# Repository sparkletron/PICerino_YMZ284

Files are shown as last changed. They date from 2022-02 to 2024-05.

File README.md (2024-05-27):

# PICerino YMZ284

Test Board and Software Library for Yamaha YMZ284 sound chips.

author: Jay Convertino  

date: 2024.04.21

license: MIT (software/Hardware)

## Release Versions
### Current
  - release_v1

### Past
  - none
  
## Requirements
### Hardware
  - KiCad
  
### Software
  - xc8 compiler
  
### General Information

Directory Listing:  

  - docs - Data documents for various ICs.
  - schematic - KiCad schematic of YMZ284 test board. See readme.md in dir for details.
  - src - Any source code for the project.
    - lib_picYMZ284 - library with test program for picerino. See readme.md in dir for details.

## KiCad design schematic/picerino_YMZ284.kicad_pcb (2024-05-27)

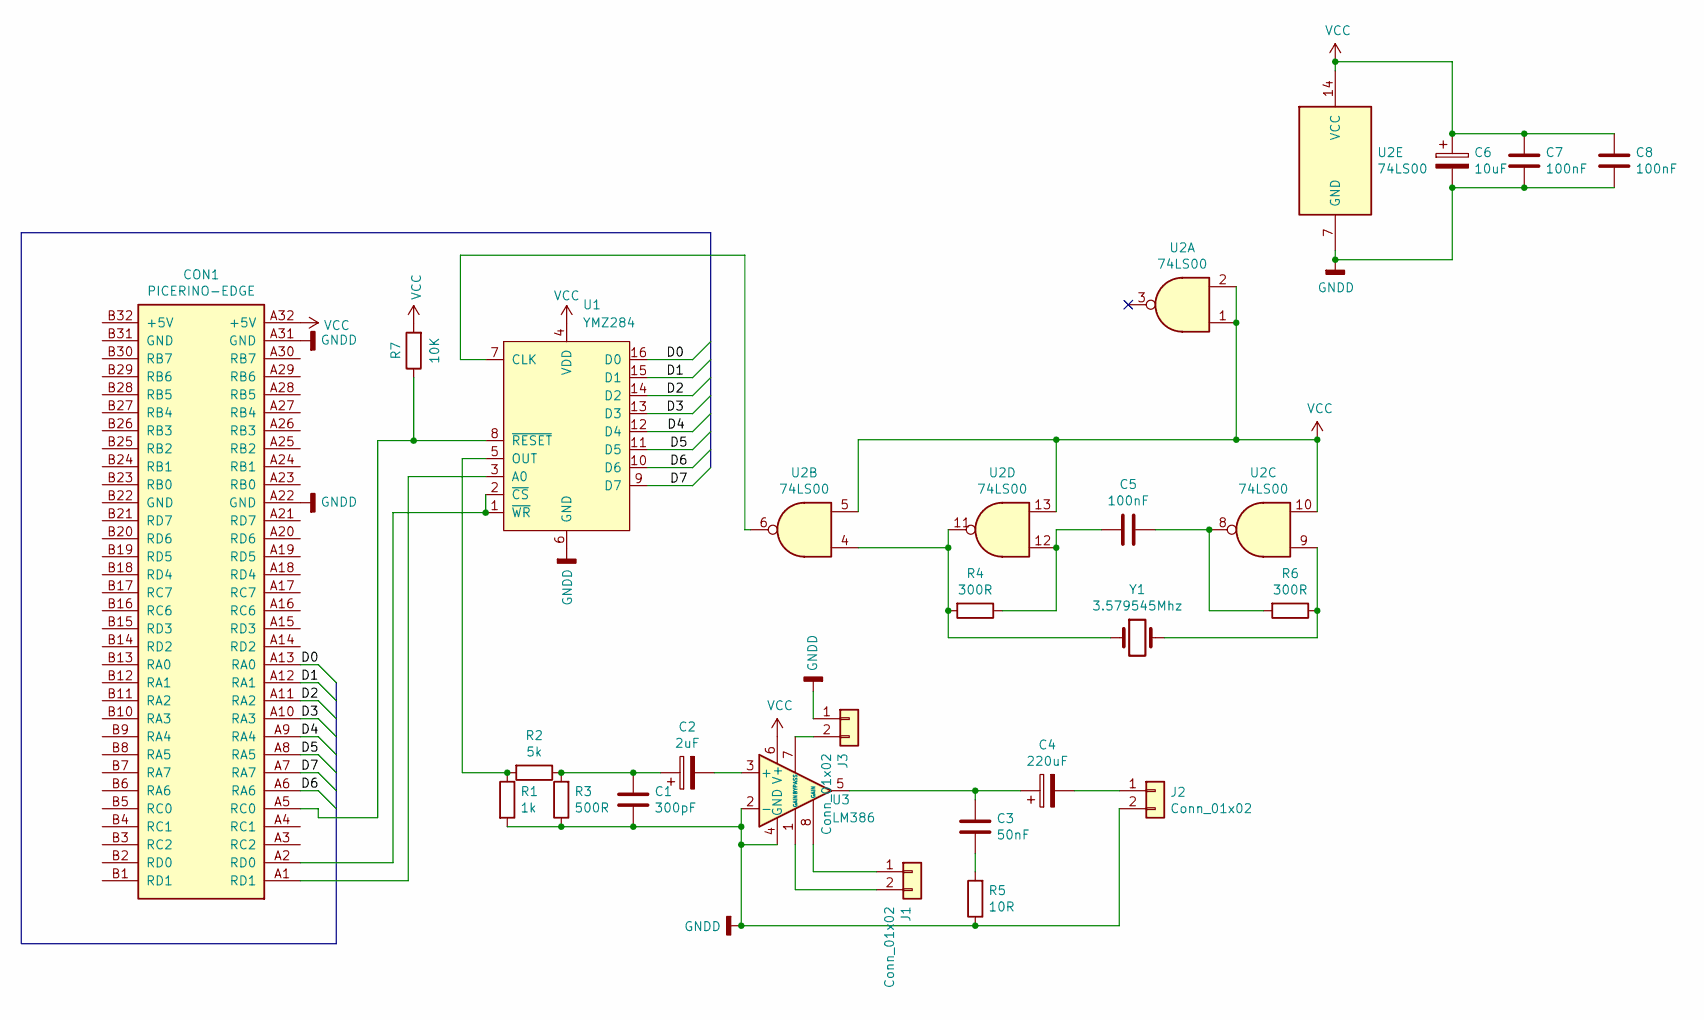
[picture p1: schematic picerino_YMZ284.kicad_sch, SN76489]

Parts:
C1: 300pF; C_Disc_D4.7mm_W2.5mm_P5.00mm
C2: 2uF; CP_Radial_D5.0mm_P2.50mm
C3: 50nF; C_Disc_D4.7mm_W2.5mm_P5.00mm
C4: 220uF; CP_Radial_D10.0mm_P5.00mm
C5, C7, C8: 100nF; C_Disc_D4.7mm_W2.5mm_P5.00mm
C6: 10uF; CP_Radial_D5.0mm_P2.50mm
CON1: PICERINO-EDGE; GENESIS-EDGE
J1, J3: Conn_01x02; PinHeader_1x02_P2.54mm_Vertical
J2: Conn_01x02; PhoenixContact_MSTBVA_2,5_2-G_1x02_P5.00mm_Vertical
R1: 1k; R_Axial_DIN0207_L6.3mm_D2.5mm_P7.62mm_Horizontal
R2: 5k; R_Axial_DIN0207_L6.3mm_D2.5mm_P7.62mm_Horizontal
R3: 500R; R_Axial_DIN0207_L6.3mm_D2.5mm_P7.62mm_Horizontal
R4, R6: 300R; R_Axial_DIN0207_L6.3mm_D2.5mm_P7.62mm_Horizontal
R5: 10R; R_Axial_DIN0207_L6.3mm_D2.5mm_P7.62mm_Horizontal
R7: 10K; R_Axial_DIN0207_L6.3mm_D2.5mm_P7.62mm_Horizontal
U1: YMZ284; DIP-16_W7.62mm_LongPads
U2: 74LS00; DIP-14_W7.62mm_LongPads
U3: LM386; DIP-8_W7.62mm_Socket_LongPads
Y1: 3.579545Mhz; Crystal_HC49-U_Vertical

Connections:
/D0: CON1.A13 (RA0), U1.16 (D0)
/D1: CON1.A12 (RA1), U1.15 (D1)
/D2: CON1.A11 (RA2), U1.14 (D2)
/D3: CON1.A10 (RA3), U1.13 (D3)
/D4: CON1.A9 (RA4), U1.12 (D4)
/D5: CON1.A8 (RA5), U1.11 (D5)
/D6: CON1.A6 (RA6), U1.10 (D6)
/D7: CON1.A7 (RA7), U1.9 (D7)
GNDD: C1.1, C6.2, C7.1, C8.1, CON1.A22 (GND), CON1.A31 (GND), J2.2, J3.1, R1.2, R3.1, R5.1, U1.6 (GND), U2.7 (GND), U3.2 (-), U3.4 (GND)
unnamed: C1.2, C2.1, R2.1, R3.2
unnamed: C3.1, R5.2
unnamed: C3.2, C4.1, U3.5
unnamed: C5.1, R6.2, U2.8
unnamed: C5.2, R4.1, U2.12
unnamed: J1.1, U3.8 (GAIN)
unnamed: J1.2, U3.1 (GAIN)
unnamed: C4.2, J2.1
unnamed: J3.2, U3.7 (BYPASS)
unnamed: R4.2, U2.4, U2.11, Y1.1
unnamed: R6.1, U2.9, Y1.2
unnamed: CON1.A1 (RD1), U1.3 (A0)
unnamed: U1.7 (CLK), U2.6
unnamed: R1.1, R2.2, U1.5 (OUT)
unnamed: CON1.A2 (RD0), U1.1 (~WR), U1.2 (~CS)
unnamed: CON1.A5 (RC0), R7.1, U1.8 (~RESET)
unnamed: C2.2, U3.3 (+)
VCC: C6.1, C7.2, C8.2, CON1.A32 (+5V), R7.2, U1.4 (VDD), U2.1, U2.2, U2.5, U2.10, U2.13, U2.14 (VCC), U3.6 (V+)

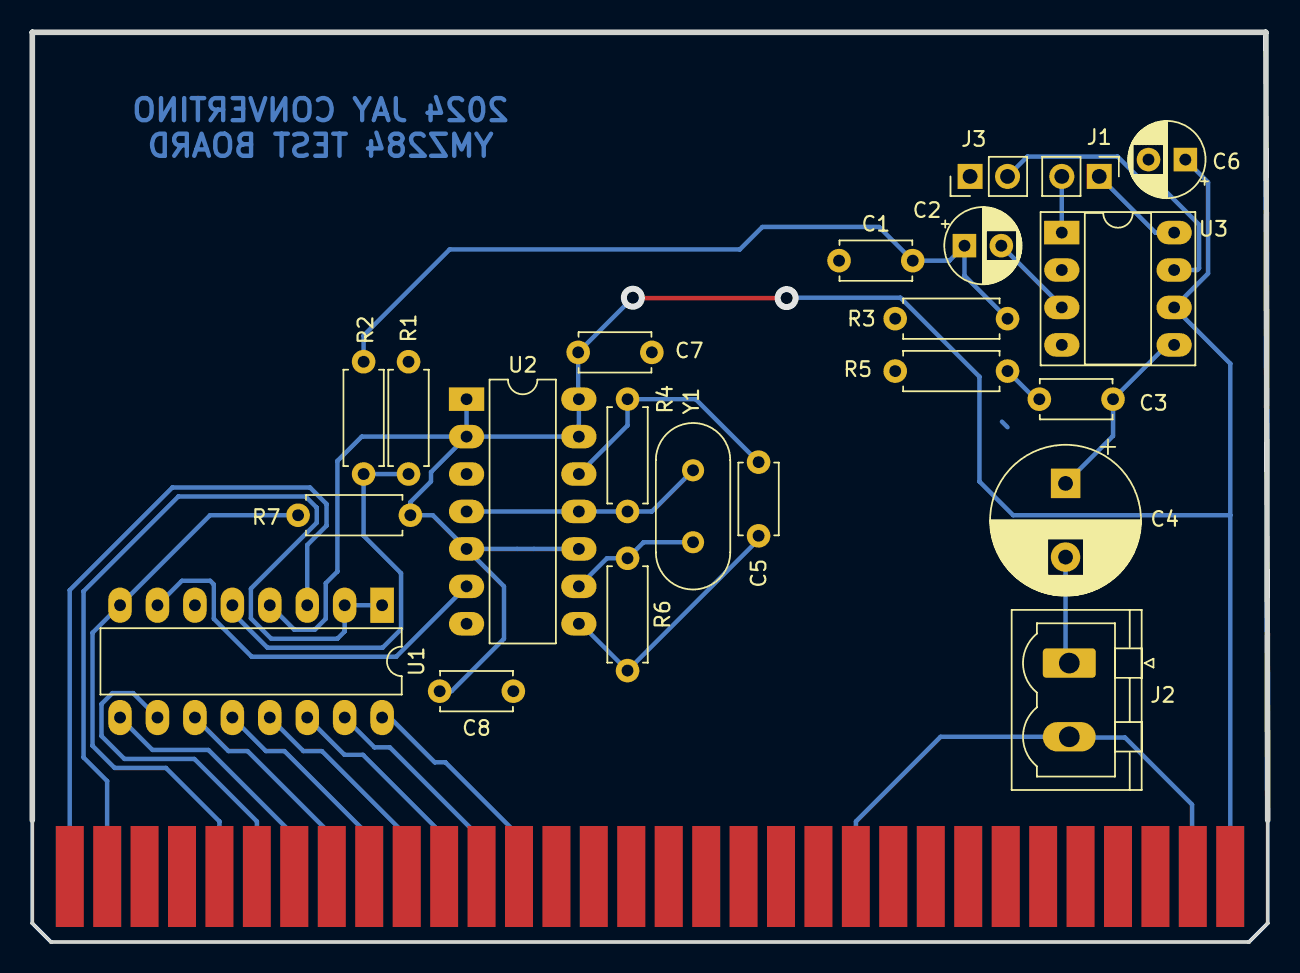
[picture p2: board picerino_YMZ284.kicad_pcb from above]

Board: 2 copper layers, 83.8 x 61.7 mm, 23 parts (0 on the bottom side), 27 nets.

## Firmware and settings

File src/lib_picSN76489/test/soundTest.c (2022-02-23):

/*******************************************************************************
 * @file      picTEST.c
 * @author    Jay Convertino
 * @date      2021.12.14
 * @brief     Test PICerino platform
 ******************************************************************************/

#include <xc.h>
#include <stdint.h>

#include <sn76489.h>

//setup to XTAL freq, for _delay macros
#define _XTAL_FREQ  48000000

/* configuration bits */
#pragma config PLLSEL   = PLL3X
#pragma config CFGPLLEN = ON
#pragma config CPUDIV   = NOCLKDIV
#pragma config LS48MHZ  = SYS48X8
#pragma config FOSC     = INTOSCIO
#pragma config PCLKEN   = OFF
#pragma config FCMEN    = OFF
#pragma config IESO     = OFF
#pragma config nPWRTEN  = OFF
#pragma config BOREN    = OFF
#pragma config BORV     = 190
#pragma config nLPBOR   = OFF
#pragma config WDTEN    = OFF
#pragma config WDTPS    = 32768
#pragma config CCP2MX   = RC1
#pragma config PBADEN   = OFF
#pragma config MCLRE    = OFF

//needed since chip is read-modify write only, and read in the same line doesn't work
uint8_t g_porteBuffer = 0;

void main(void) 
{
  uint8_t  index = 0;
  uint16_t freq = 0;
  uint8_t  attn = 0;
  uint8_t  shiftRate = 0;
  
  struct s_sn76489 sn76489;

  /* OSCCON SETUP */
  OSCCONbits.IRCF = 0x7;
  OSCCONbits.OSTS = 0;
  OSCCONbits.SCS  = 0x3;

  OSCCON2bits.PLLEN = 1;

  /* PORT E SETUP */
  INTCON2bits.nRBPU = 1;

  /* disable analog inputs */
  ANSELA = 0;
  ANSELC = 0;
  ANSELD = 0;
  ANSELE = 0;

  /* Port E set all to output */
  TRISE = 0;

  LATE = 0;

  g_porteBuffer = 1;

  /* wait for chip to be ready */
  __delay_ms(10);

  initSN76489port(&sn76489, &TRISA, &TRISD, &TRISC, 6, 7, 0);

  initSN76489(&sn76489, &LATA, &LATD, &PORTC);

  /* voice tests */
  for(index = 1; index <= 3; index++)
  {
    attn = 0;
    freq = 0;
    
    LATE = (unsigned)(1 << (index-1));
    
    setSN76489voice_attn(&sn76489, index, 2);
    
    /* voice freq test */
    do
    {
      setSN76489voice_freq(&sn76489, index, freq);
      
      __delay_ms(5);
      
      freq++;
      
    } while(freq < (1 << 10));
    
    setSN76489voice_freq(&sn76489, index, 254);
    
    /* voice attn test */
    do
    {
      setSN76489voice_attn(&sn76489, index, attn);
      
      __delay_ms(500);
      
      attn++;
      
    } while(attn < (1 << 4));
  }
 
  /* test noise */
  attn = 0;
  
  LATE = 3;
  
  setSN76489noise_attn(&sn76489, 2);
  
  /** Periodic noise **/
  do
  {
    setSN76489noiseCtrl(&sn76489, 0, shiftRate);
    
    __delay_ms(2000);
    
    shiftRate++;
    
  } while(shiftRate < (1 << 2));
  
  /* noise attn test */
  do
  {
    setSN76489noise_attn(&sn76489, attn);
    
    __delay_ms(500);
    
    attn++;
    
  } while(attn < (1 << 4));
  
  shiftRate = 0;
  
  LATE = 6;
  
  setSN76489noise_attn(&sn76489, 2);
  
  /** White noise **/
  do
  {
    setSN76489noiseCtrl(&sn76489, 1, shiftRate);
    
    __delay_ms(2000);
    
    shiftRate++;
    
  } while(shiftRate < (1 << 2));
  
  attn = 0;
  
  /* noise attn test */
  do
  {
    setSN76489noise_attn(&sn76489, attn);
    
    __delay_ms(500);
    
    attn++;
    
  } while(attn < (1 << 4));
  
  /* done testing */
  LATE = 0;
  
  for(;;)
  {
    LATE = g_porteBuffer;
    g_porteBuffer = (g_porteBuffer == 4 ? 1 : (unsigned)g_porteBuffer << 1);
    __delay_ms(100);
  }
}

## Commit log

2022-01-28 fixed bug in io port ansel* setup for D and A ports. Fixed shift amount for reg address (was old from messed up board)
    [soundTest.c]
2022-01-29 updated board to RC port for ready, since RC has pin change interrupts.
2022-01-29 updated kicad schematic and pcb so ready is tied to RC7
    [picerino_sn76489AN.kicad_pcb, picerino_sn76489AN.sch]
2022-01-29 ready on wrong pin
    [soundTest.c]
2022-01-31 moved header file and added doxygen to ignore
    [dox.cfg]
2022-02-20 reverse bit order on pcb to remove software reversal
    [picerino_sn76489AN.kicad_pcb, picerino_sn76489AN.sch]
2022-02-21 fixed test appliction and simplified library interface
    [soundTest.c]
2022-02-21 fixed pcb so bits are reversed as they should be
    [picerino_sn76489AN.kicad_pcb, picerino_sn76489AN.sch]
2022-02-21 don't add gerbers to repo, update pcb gerber path in kicad
    [picerino_sn76489AN.kicad_pcb]
2022-02-23 final tweaks to code, one note... the while loop isn't great for checking the ready. Its too slow, but its universal so using this code on different uC is trivial. Optimize sendData for your applicat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
    [soundTest.c]
2022-07-05 updated kicad
    [picerino_sn76489AN.kicad_sch, picerino_sn76489AN.sch]
2022-11-13 updated schematics to kicad v6
    [picerino_sn76489AN.kicad_pcb]
2023-01-16 added mit license
    [picerino_sn76489AN.kicad_sch]
2024-04-21 first update to YMZ284 from TI sound chip
    [picerino_YMZ284.kicad_pcb, picerino_YMZ284.kicad_sch, picerino_sn76489AN.kicad_pcb]
2024-05-27 first version with library conversion. main test app still needs to be converted
    [dox.cfg, picerino_YMZ284.kicad_pcb]
